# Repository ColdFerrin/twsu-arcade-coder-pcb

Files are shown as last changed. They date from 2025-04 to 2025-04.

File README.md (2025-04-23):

# twsu-arcade-coder-pcb

An open source repository for replicating the board schematics and layout of Tech Will Save Us's ESP32-powered Arcade Coder RGB input matrix.

This project is viewable in KiCad 9.0+

I am not an electrical engineer, this is my best guess at replicating the schematics and layout of the board.  

## Community

Following [a very generous sharing of dozens of Arcade Coders](https://www.reddit.com/r/LinusTechTips/comments/1jgk9cr/how_can_i_stop_all_of_this_from_becoming_ewaste/), there is now a community of developers working on developing software for this board on [Discord](https://discord.gg/QWCUWKAqts) (if this URL does not work please message someone in the reddit thread who has joined).
If you join the community please make an effort to share your discoveries in a public space for future preservation.

## How it works

- 9 daisy chained HC595 chips are daisy-chained and used to control 24 RGB LEDs (two of the twelve rows) from 3 ESP32 pins
- 6 multiplexing channels are used to control the rows which the HC595s are in control of, this is done with an IC2012 (LS138) which requires 3 pins; the other 2 channels uses are unknown
- buttons on matrix are partially handled by 6 GPIO pins which are grouped in correspondence with the multiplexed LED channels (seemingly also partially handled by values being distorted by red LEDs)
- 2 status LEDs on the rear of the device are directly controlled by a GPIO pin each, as is the home button on the side
- accelerometer which I have not tested

### Pinout

HC595:
- Data: GPIO5
- Clock: GPIO17
- Latch: GPIO16
- OE: GPIO4 

ICN2012 (LS138, controls multiplexing to allow control of all 144 RGB LEDs):
- A0: GPIO19
- A1: GPIO18
- A2: GPIO21
- E1: 3.3v
- E2: GND (after a chain of resistors)

Button inputs (tracks if any button in row is pressed):
- 6 and 12: GPIO32
- 5 and 11: GPIO33
- 4 and 10: GPIO34
- 3 and 9: GPIO35
- 2 and 8: GPIO36
- 1 and 7: GPIO39

Other:
- LED1: GPIO22
- LED2: GPIO23
- Home: GPIO2 (seems unreliable)
- Motion sensor: GPIO27/GPIO26 for possible accelerometer in middle of board

Note: Usage of GPIO4 may impact ability to use Wifi from what I can see, will need to verify and see if it can be worked around.

## Errata

The project is currently schematics only, and currently only has the LED matrix and logic chips. I am working on figuring out the wiring of the button matrix, but that is more complicated as it uses some kind of resister ladder.

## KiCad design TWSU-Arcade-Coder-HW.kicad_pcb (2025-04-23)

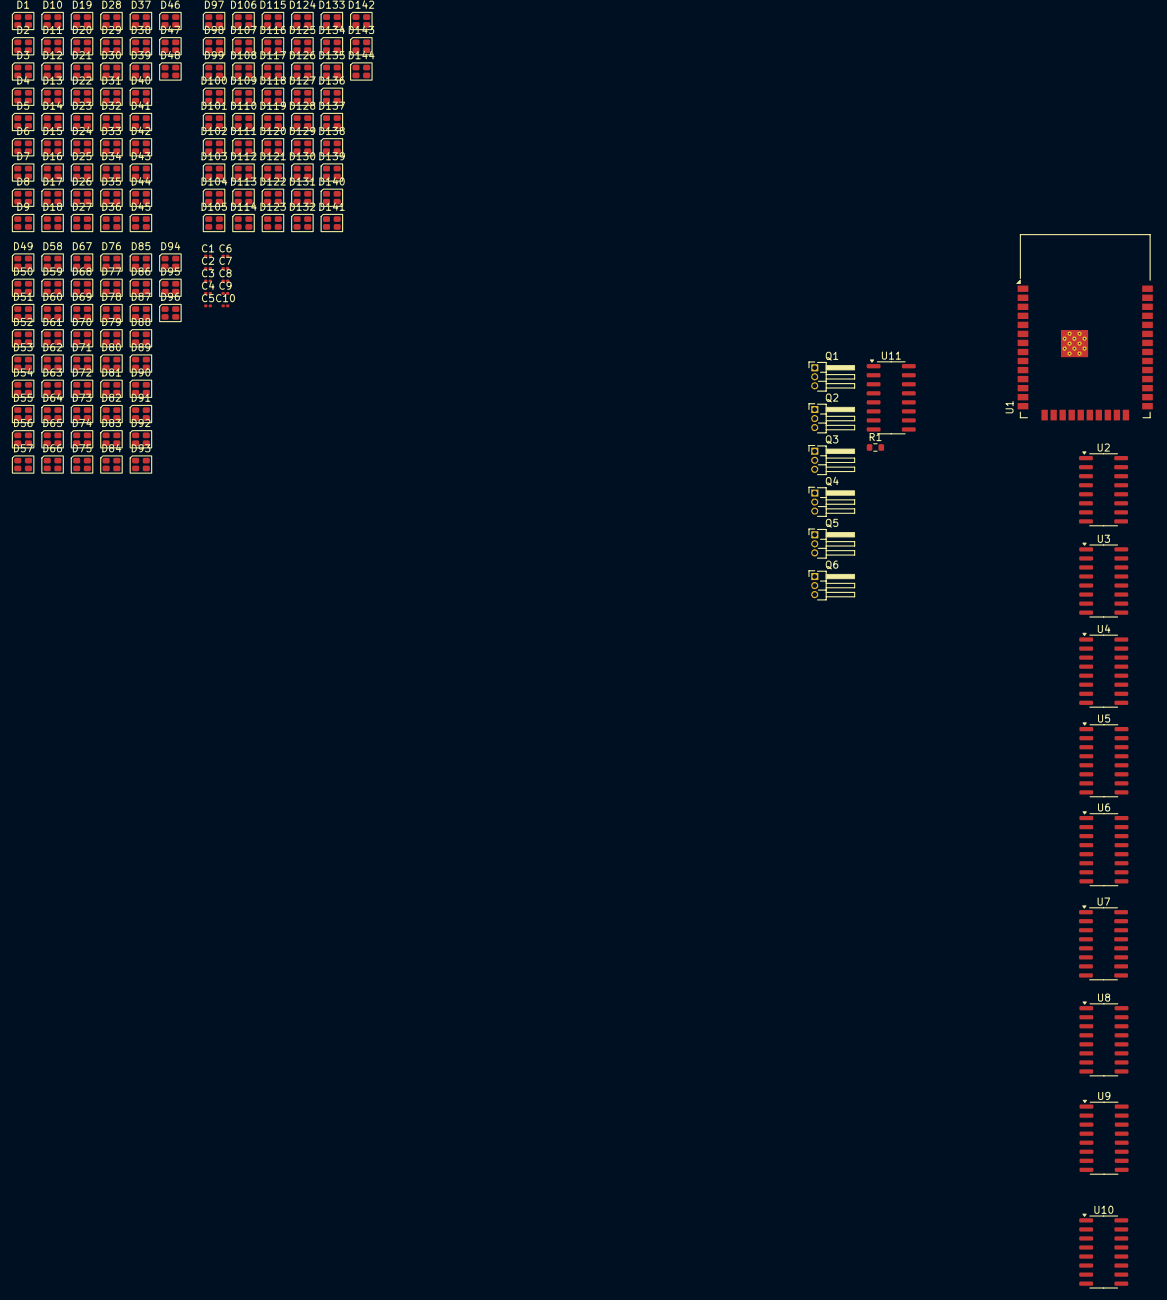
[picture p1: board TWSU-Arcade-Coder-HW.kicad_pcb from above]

Board: 2 copper layers, 172 parts (0 on the bottom side), 65 nets, no tracks yet.

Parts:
C1, C2, C3, C4, C5, C6, C7, C8, C9, C10: C; C_0201_0603Metric
D1, D2, D3, D4, D5, D6, D7, D8, D9, D10, D11, D12, D13, D14, D15, D16, D17, D18, D19, D20, D21, D22, D23, D24, D25, D26, D27, D28, D29, D30, D31, D32, D33, D34, D35, D36, D37, D38, D39, D40, D41, D42, D43, D44, D45, D46, D47, D48, D49, D50, D51, D52, D53, D54, D55, D56, D57, D58, D59, D60, D61, D62, D63, D64, D65, D66, D67, D68, D69, D70, D71, D72, D73, D74, D75, D76, D77, D78, D79, D80, D81, D82, D83, D84, D85, D86, D87, D88, D89, D90, D91, D92, D93, D94, D95, D96, D97, D98, D99, D100, D101, D102, D103, D104, D105, D106, D107, D108, D109, D110, D111, D112, D113, D114, D115, D116, D117, D118, D119, D120, D121, D122, D123, D124, D125, D126, D127, D128, D129, D130, D131, D132, D133, D134, D135, D136, D137, D138, D139, D140, D141, D142, D143, D144: LED_ARGB; LED_Cree-PLCC4_2x2mm_CW
Q1, Q2, Q3, Q4, Q5, Q6: PMOS; PinHeader_1x03_P1.27mm_Horizontal
R1: R; R_0603_1608Metric
U1: ESP32-WROOM-32D
U2, U3, U4, U5, U6, U7, U8, U9, U10: 74HC595; SOIC-16_3.9x9.9mm_P1.27mm
U11: SOIC-16_3.9x9.9mm_P1.27mm

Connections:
+3.3V: U1.2 (VDD), U2.16 (VCC), U3.16 (VCC), U4.16 (VCC), U5.16 (VCC), U6.16 (VCC), U7.16 (VCC), U8.16 (VCC), U9.16 (VCC), U10.16 (VCC)
+5V: Q1.1 (D), Q2.1 (D), Q3.1 (D), Q4.1 (D), Q5.1 (D), Q6.1 (D), U11.1 (VCC), U11.9 (VCC)
/595 Data: U1.29 (IO5), U2.14 (SER)
/595 OE: U1.26 (IO4), U2.13 (~OE), U3.13 (~OE), U4.13 (~OE), U5.13 (~OE), U6.13 (~OE), U7.13 (~OE), U8.13 (~OE), U9.13 (~OE), U10.13 (~OE)
/595 R CLK: U1.27 (IO16), U2.12 (RCLK), U3.12 (RCLK), U4.12 (RCLK), U5.12 (RCLK), U6.12 (RCLK), U7.12 (RCLK), U8.12 (RCLK), U9.12 (RCLK), U10.12 (RCLK)
/595 SR CLK: R1.1, U2.11 (SRCLK), U3.11 (SRCLK), U4.11 (SRCLK), U5.11 (SRCLK), U6.11 (SRCLK), U7.11 (SRCLK), U8.11 (SRCLK), U9.11 (SRCLK), U10.11 (SRCLK)
/Col addr 0: U1.31 (IO19), U11.15 (A0)
/Col addr 1: U1.30 (IO18), U11.16 (A1)
/Col addr 2: U1.33 (IO21), U11.2 (A2)
GND: C1.2, C2.1, C3.1, C4.1, C5.1, C6.1, C7.1, C8.1, C9.1, C10.1, U1.1 (GND), U1.15 (GND), U1.38 (GND), U1.39 (GND), U2.8 (GND), U3.8 (GND), U4.8 (GND), U5.8 (GND), U6.8 (GND), U7.8 (GND), U8.8 (GND), U9.8 (GND), U10.8 (GND), U11.8 (GND)
unnamed: C1.1, R1.2, U1.28 (IO17)
unnamed: U2.9 (QH'), U3.14 (SER)
unnamed: C2.2, U2.10 (~SRCLR)
unnamed: U3.9 (QH'), U4.14 (SER)
unnamed: C3.2, U3.10 (~SRCLR)
unnamed: U4.9 (QH'), U5.14 (SER)
unnamed: C4.2, U4.10 (~SRCLR)
unnamed: U5.9 (QH'), U6.14 (SER)
unnamed: C5.2, U5.10 (~SRCLR)
unnamed: U6.9 (QH'), U7.14 (SER)
unnamed: C9.2, U6.10 (~SRCLR)
unnamed: U7.9 (QH'), U8.14 (SER)
unnamed: C8.2, U7.10 (~SRCLR)
unnamed: U8.9 (QH'), U9.14 (SER)
unnamed: C7.2, U8.10 (~SRCLR)
unnamed: C6.2, U9.10 (~SRCLR)
unnamed: U9.9 (QH'), U10.14 (SER)
unnamed: C10.2, U10.10 (~SRCLR)
RS1: D1.1 (A), D2.1 (A), D3.1 (A), D4.1 (A), D5.1 (A), D6.1 (A), D7.1 (A), D8.1 (A), D9.1 (A), D10.1 (A), D11.1 (A), D12.1 (A), D51.1 (A), D55.1 (A), D59.1 (A), D63.1 (A), D67.1 (A), D71.1 (A), D75.1 (A), D79.1 (A), D83.1 (A), D87.1 (A), D91.1 (A), D95.1 (A), U11.5 (OUT_2)
RS2: D13.1 (A), D14.1 (A), D15.1 (A), D16.1 (A), D17.1 (A), D18.1 (A), D19.1 (A), D20.1 (A), D21.1 (A), D22.1 (A), D23.1 (A), D24.1 (A), D52.1 (A), D56.1 (A), D60.1 (A), D64.1 (A), D68.1 (A), D72.1 (A), D76.1 (A), D80.1 (A), D84.1 (A), D88.1 (A), D92.1 (A), D96.1 (A), U11.6 (OUT_3)
RS3: D25.1 (A), D26.1 (A), D27.1 (A), D28.1 (A), D29.1 (A), D30.1 (A), D31.1 (A), D32.1 (A), D33.1 (A), D34.1 (A), D35.1 (A), D36.1 (A), D97.1 (A), D101.1 (A), D105.1 (A), D109.1 (A), D113.1 (A), D117.1 (A), D121.1 (A), D125.1 (A), D129.1 (A), D133.1 (A), D137.1 (A), D141.1 (A), U11.12 (OUT_5)
RS4: D37.1 (A), D38.1 (A), D39.1 (A), D40.1 (A), D41.1 (A), D42.1 (A), D43.1 (A), D44.1 (A), D45.1 (A), D46.1 (A), D47.1 (A), D48.1 (A), D98.1 (A), D102.1 (A), D106.1 (A), D110.1 (A), D114.1 (A), D118.1 (A), D122.1 (A), D126.1 (A), D130.1 (A), D134.1 (A), D138.1 (A), D142.1 (A), U11.11 (OUT_4)
RS5: D49.1 (A), D53.1 (A), D57.1 (A), D61.1 (A), D65.1 (A), D69.1 (A), D73.1 (A), D77.1 (A), D81.1 (A), D85.1 (A), D89.1 (A), D93.1 (A), D99.1 (A), D103.1 (A), D107.1 (A), D111.1 (A), D115.1 (A), D119.1 (A), D123.1 (A), D127.1 (A), D131.1 (A), D135.1 (A), D139.1 (A), D143.1 (A), U11.4 (OUT_1)
RS6: D50.1 (A), D54.1 (A), D58.1 (A), D62.1 (A), D66.1 (A), D70.1 (A), D74.1 (A), D78.1 (A), D82.1 (A), D86.1 (A), D90.1 (A), D94.1 (A), D100.1 (A), D104.1 (A), D108.1 (A), D112.1 (A), D116.1 (A), D120.1 (A), D124.1 (A), D128.1 (A), D132.1 (A), D136.1 (A), D140.1 (A), D144.1 (A), U11.13 (OUT_6)
s1b1: D12.4 (BK), D24.4 (BK), D36.4 (BK), D48.4 (BK), D93.4 (BK), D94.4 (BK), U8.15 (QA)
s1b2: D11.4 (BK), D23.4 (BK), D35.4 (BK), D47.4 (BK), D89.4 (BK), D90.4 (BK), U8.1 (QB)
s1b3: D10.4 (BK), D22.4 (BK), D34.4 (BK), D46.4 (BK), D85.4 (BK), D86.4 (BK), U8.2 (QC)
s1b4: D9.4 (BK), D21.4 (BK), D33.4 (BK), D45.4 (BK), D81.4 (BK), D82.4 (BK), U8.3 (QD)
s1b5: D8.4 (BK), D20.4 (BK), D32.4 (BK), D44.4 (BK), D77.4 (BK), D78.4 (BK), U8.4 (QE)
s1b6: D7.4 (BK), D19.4 (BK), D31.4 (BK), D43.4 (BK), D73.4 (BK), D74.4 (BK), U8.5 (QF)
s1b7: D6.4 (BK), D18.4 (BK), D30.4 (BK), D42.4 (BK), D69.4 (BK), D70.4 (BK), U8.6 (QG)
s1b8: D5.4 (BK), D17.4 (BK), D29.4 (BK), D41.4 (BK), D65.4 (BK), D66.4 (BK), U8.7 (QH)
s1g1: D12.3 (GK), D24.3 (GK), D36.3 (GK), D48.3 (GK), D93.3 (GK), D94.3 (GK), U10.15 (QA)
s1g2: D11.3 (GK), D23.3 (GK), D35.3 (GK), D47.3 (GK), D89.3 (GK), D90.3 (GK), U10.1 (QB)
s1g3: D10.3 (GK), D22.3 (GK), D34.3 (GK), D46.3 (GK), D85.3 (GK), D86.3 (GK), U10.2 (QC)
s1g4: D9.3 (GK), D21.3 (GK), D33.3 (GK), D45.3 (GK), D81.3 (GK), D82.3 (GK), U10.3 (QD)
s1g5: D8.3 (GK), D20.3 (GK), D32.3 (GK), D44.3 (GK), D77.3 (GK), D78.3 (GK), U10.4 (QE)
s1g6: D7.3 (GK), D19.3 (GK), D31.3 (GK), D43.3 (GK), D73.3 (GK), D74.3 (GK), U10.5 (QF)
s1g7: D6.3 (GK), D18.3 (GK), D30.3 (GK), D42.3 (GK), D69.3 (GK), D70.3 (GK), U10.6 (QG)
s1g8: D5.3 (GK), D17.3 (GK), D29.3 (GK), D41.3 (GK), D65.3 (GK), D66.3 (GK), U10.7 (QH)
s1r1: D12.2 (RK), D24.2 (RK), D36.2 (RK), D48.2 (RK), D93.2 (RK), D94.2 (RK), U9.15 (QA)
s1r2: D11.2 (RK), D23.2 (RK), D35.2 (RK), D47.2 (RK), D89.2 (RK), D90.2 (RK), U9.1 (QB)
s1r3: D10.2 (RK), D22.2 (RK), D34.2 (RK), D46.2 (RK), D85.2 (RK), D86.2 (RK), U9.2 (QC)
s1r4: D9.2 (RK), D21.2 (RK), D33.2 (RK), D45.2 (RK), D81.2 (RK), D82.2 (RK), U9.3 (QD)
s1r5: D8.2 (RK), D20.2 (RK), D32.2 (RK), D44.2 (RK), D77.2 (RK), D78.2 (RK), U9.4 (QE)
s1r6: D7.2 (RK), D19.2 (RK), D31.2 (RK), D43.2 (RK), D73.2 (RK), D74.2 (RK), U9.5 (QF)
s1r7: D6.2 (RK), D18.2 (RK), D30.2 (RK), D42.2 (RK), D69.2 (RK), D70.2 (RK), U9.6 (QG)
s1r8: D5.2 (RK), D17.2 (RK), D29.2 (RK), D41.2 (RK), D65.2 (RK), D66.2 (RK), U9.7 (QH)
s2b1: D4.4 (BK), D16.4 (BK), D28.4 (BK), D40.4 (BK), D61.4 (BK), D62.4 (BK), U5.15 (QA)
s2g1: D4.3 (GK), D16.3 (GK), D28.3 (GK), D40.3 (GK), D61.3 (GK), D62.3 (GK), U7.15 (QA)
s2r1: D4.2 (RK), D16.2 (RK), D28.2 (RK), D40.2 (RK), D61.2 (RK), D62.2 (RK), U6.15 (QA)
s2r2: D3.2 (RK), D15.2 (RK), D27.2 (RK), D39.2 (RK), D57.2 (RK), D58.2 (RK), U6.1 (QB)
s2r3: D2.2 (RK), D14.2 (RK), D26.2 (RK), D38.2 (RK), D53.2 (RK), D54.2 (RK), U6.2 (QC)
s2r4: D1.2 (RK), D13.2 (RK), D25.2 (RK), D37.2 (RK), D49.2 (RK), D50.2 (RK), U6.3 (QD)
s2r5: D63.2 (RK), D64.2 (RK), D109.2 (RK), D110.2 (RK), D111.2 (RK), D112.2 (RK), U6.4 (QE)
